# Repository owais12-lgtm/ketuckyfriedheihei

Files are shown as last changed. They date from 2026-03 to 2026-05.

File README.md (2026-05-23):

# ketuckyfriedheihei

https://github.com/user-attachments/assets/ab107a92-7bb6-4f32-aefd-921b1ff62dd6

# about

This keyboard has 74 regular keys, 8 programmable macro keys, and 1 switch within the rotary encoder

# Images







# BOM

| Name | Purpose | Quantity | Total Cost (USD) | Link | Distributor |
|---|---|---|---|---|---|
| PCB | PCB | 1 | $60.00 | [lioncircuits.com](https://www.lioncircuits.com/quote) | Lion Circuits |
| Keycaps | Keycaps | 1 | $30.00 | [curiositycaps.in](https://curiositycaps.in/products/polar-day-line-crack-side-backlit-cherry-keycaps) | Curiosity Caps |
| Akko V3 Silver | Switches | 2 | $32.00 | [stackskb.com](https://stackskb.com/store/akko-v3-silver-pro-switch-pack-of-45/) | StacksKB |
| OLED | OLED | 1 | $2.00 | [robu.in](https://robu.in/product/0-91-inch-128x32-i2c-iic-serial-blue-oled-lcd-display-module/) | Robu |
| Raspberry Pi Pico | MCU | 1 | $5.00 | [robu.in](https://robu.in/product/raspberry-pi-pico/) | Robu |

# CAD files

https://www.tinkercad.com/things/lyZ20fdyAEX-surprising-snicket

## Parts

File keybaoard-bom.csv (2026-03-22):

Name | Purpose | Quantity | Total Cost (USD) | Link | Distributor
pcb | pcb | 1 | 0.00 | https://www.lioncircuits.com/quote | lion circuits
keycaps | keycaps | 1 | 30.00 | https://curiositycaps.in/products/polar-day-line-crack-side-backlit-cherry-keycaps | curiosity caps
Akko V3 Silver | switches | 2 | 32.00 | https://stackskb.com/store/akko-v3-silver-pro-switch-pack-of-45/ | stackskb
OLED | oled | 1 | 2.00 | https://robu.in/product/0-91-inch-128x32-i2c-iic-serial-blue-oled-lcd-display-module/ | robu
Raspberry Pi Pico | MCU | 1 | 5.00 | https://robu.in/product/raspberry-pi-pico/ | robu

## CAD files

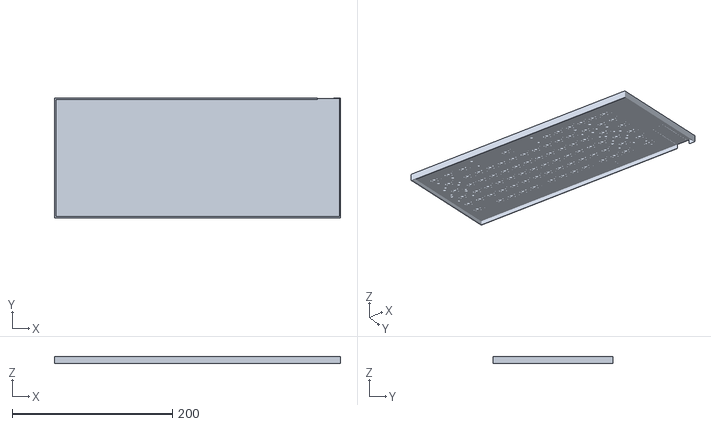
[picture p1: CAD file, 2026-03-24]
CAD/Surprising Snicket(2).stl
357.0 x 150.0 x 9.10

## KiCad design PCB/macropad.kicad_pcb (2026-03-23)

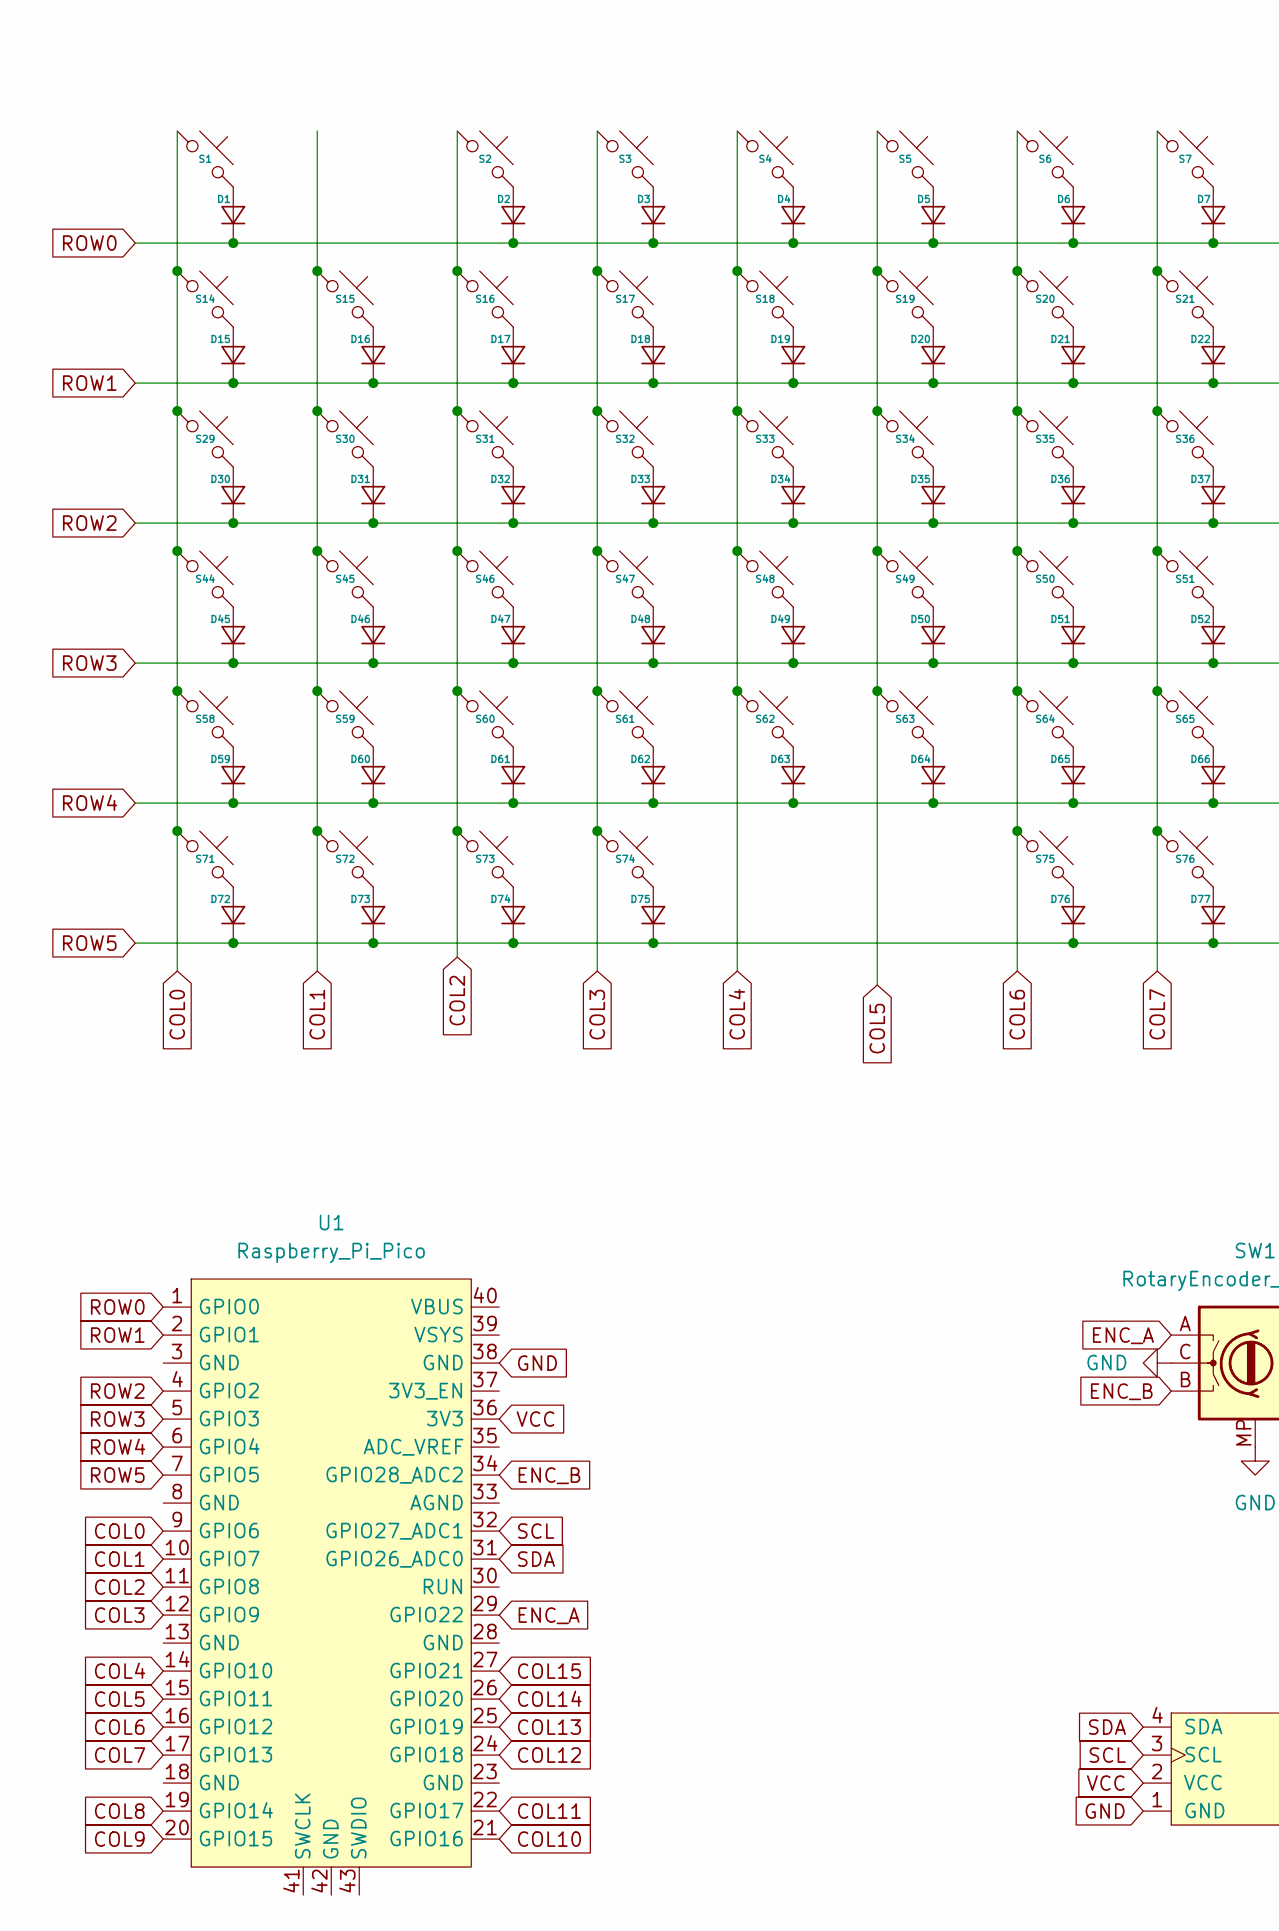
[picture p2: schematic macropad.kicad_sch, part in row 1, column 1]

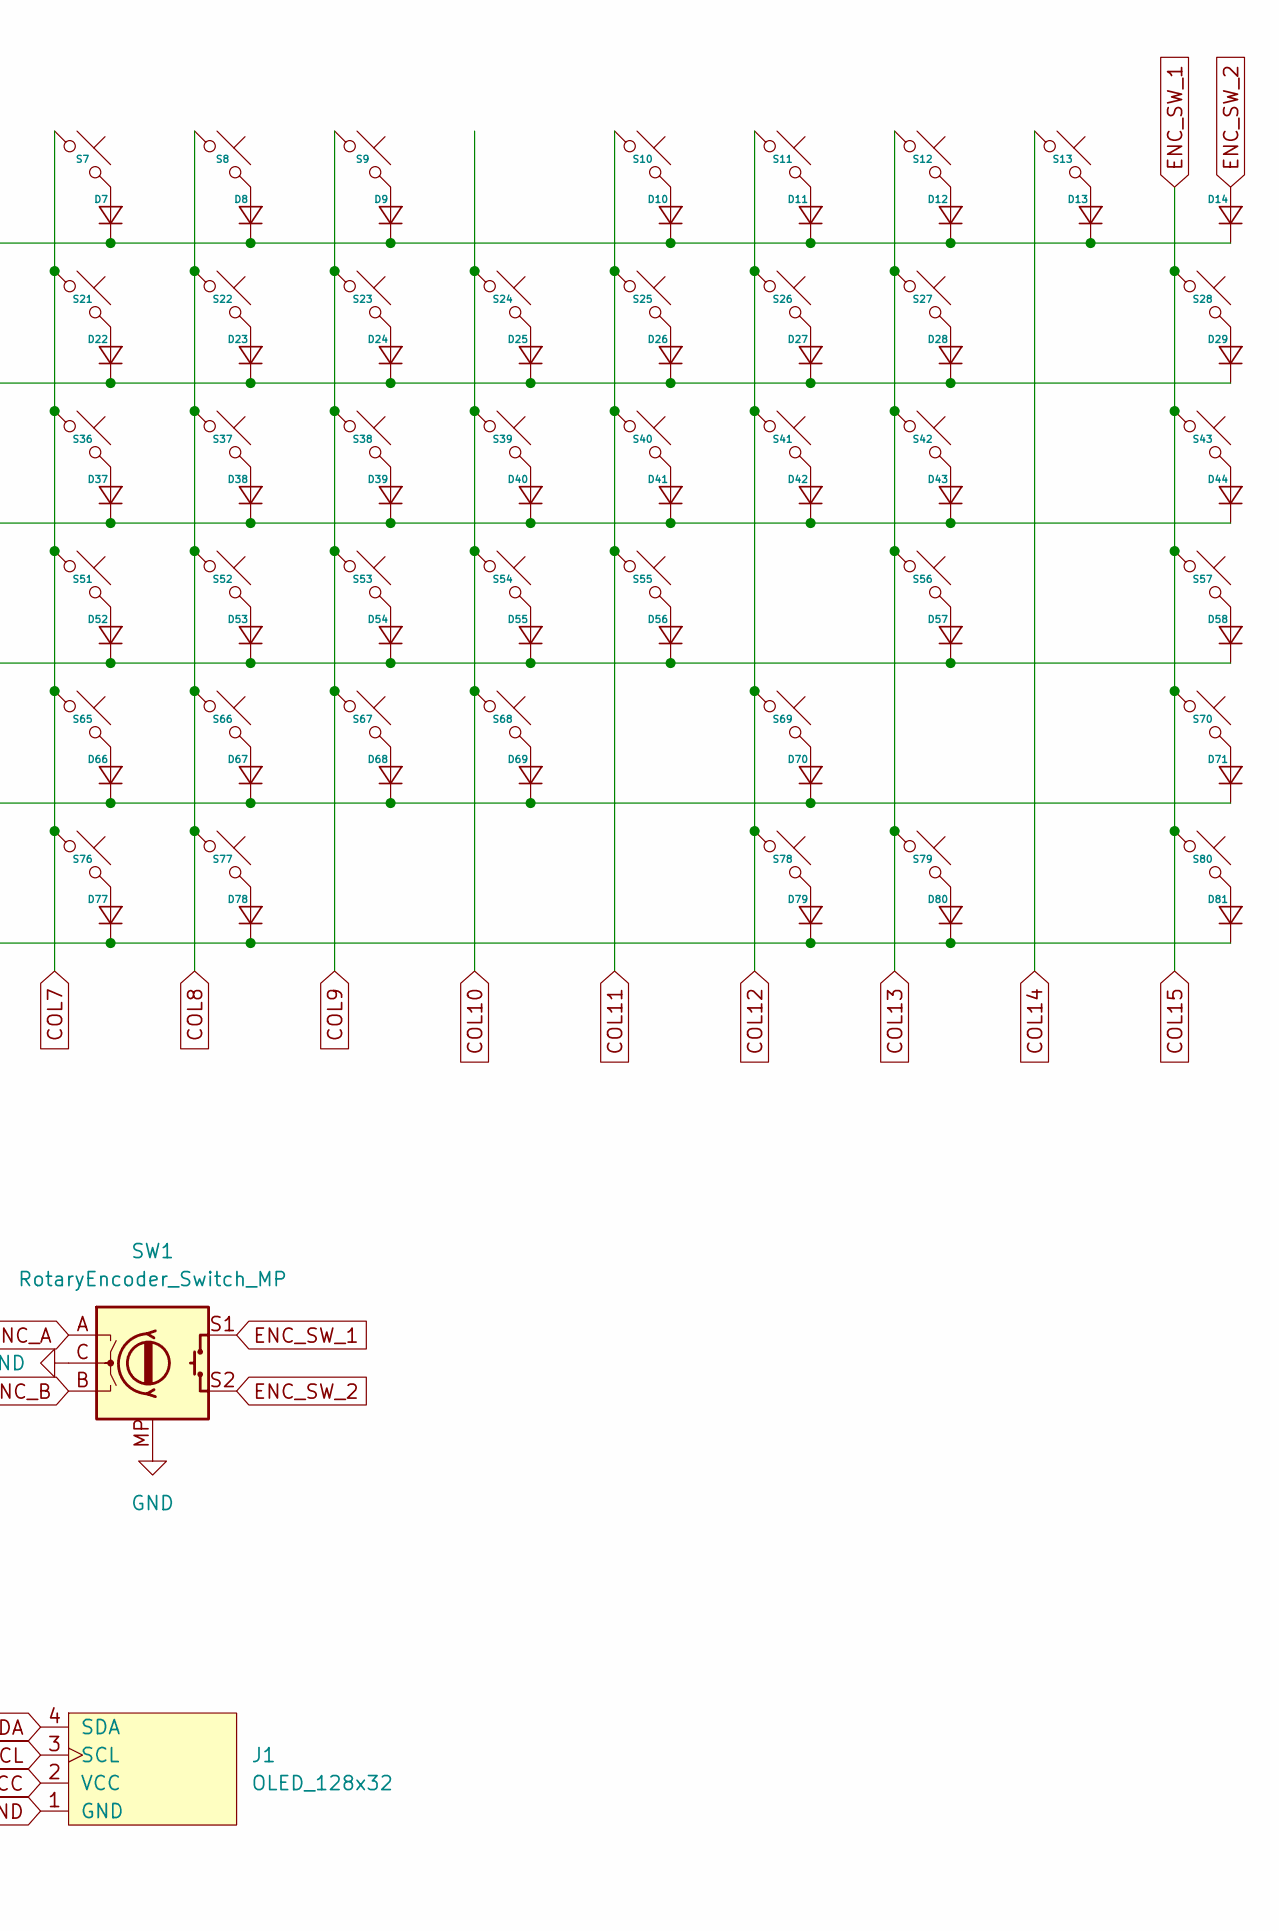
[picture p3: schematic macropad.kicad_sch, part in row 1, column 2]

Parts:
D1, D2, D3, D4, D5, D6, D7, D8, D9, D10, D11, D12, D13, D14, D15, D16, D17, D18, D19, D20, D21, D22, D23, D24, D25, D26, D27, D28, D29, D30, D31, D32, D33, D34, D35, D36, D37, D38, D39, D40, D41, D42, D43, D44, D45, D46, D47, D48, D49, D50, D51, D52, D53, D54, D55, D56, D57, D58, D59, D60, D61, D62, D63, D64, D65, D66, D67, D68, D69, D70, D71, D72, D73, D74, D75, D76, D77, D78, D79, D80, D81: Diode_DO-35
J1: OLED_128x32
S1, S2, S3, S4, S5, S6, S7, S8, S9, S10, S11, S12, S13, S14, S15, S16, S17, S18, S19, S20, S21, S22, S23, S24, S25, S26, S27, S28, S29, S30, S31, S32, S33, S34, S35, S36, S37, S38, S39, S40, S41, S42, S43, S44, S45, S46, S47, S48, S49, S50, S51, S52, S53, S54, S55, S56, S57, S58, S59, S60, S61, S62, S63, S64, S65, S66, S67, S68, S69, S70, S71, S72, S73, S74, S75, S76, S77, S78, S79, S80: MX_PCB_1.00u
SW1: RotaryEncoder_Switch_MP; RotaryEncoder_Alps_EC11E-Switch_Vertical_H20mm_MountingHoles
U1: Raspberry_Pi_Pico

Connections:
COL0: S1.1, S14.1, S29.1, S44.1, S58.1, S71.1, U1.9 (GPIO6)
COL1: S15.1, S30.1, S45.1, S59.1, S72.1, U1.10 (GPIO7)
COL2: S2.1, S16.1, S31.1, S46.1, S60.1, S73.1, U1.11 (GPIO8)
COL3: S3.1, S17.1, S32.1, S47.1, S61.1, S74.1, U1.12 (GPIO9)
COL4: S4.1, S18.1, S33.1, S48.1, S62.1, U1.14 (GPIO10)
COL5: S5.1, S19.1, S34.1, S49.1, S63.1, U1.15 (GPIO11)
COL6: S6.1, S20.1, S35.1, S50.1, S64.1, S75.1, U1.16 (GPIO12)
COL7: S7.1, S21.1, S36.1, S51.1, S65.1, S76.1, U1.17 (GPIO13)
COL8: S8.1, S22.1, S37.1, S52.1, S66.1, S77.1, U1.19 (GPIO14)
COL9: S9.1, S23.1, S38.1, S53.1, S67.1, U1.20 (GPIO15)
COL10: S24.1, S39.1, S54.1, S68.1, U1.21 (GPIO16)
COL11: S10.1, S25.1, S40.1, S55.1, U1.22 (GPIO17)
COL12: S11.1, S26.1, S41.1, S69.1, S78.1, U1.24 (GPIO18)
COL13: S12.1, S27.1, S42.1, S56.1, S79.1, U1.25 (GPIO19)
COL14: S13.1, U1.26 (GPIO20)
COL15: S28.1, S43.1, S57.1, S70.1, S80.1, SW1.S1, U1.27 (GPIO21)
ENC_A: SW1.A, U1.29 (GPIO22)
ENC_B: SW1.B, U1.34 (GPIO28_ADC2)
ENC_SW_2: D14.2 (A), SW1.S2
GND: J1.1 (GND), SW1.C, SW1.MP, U1.38 (GND)
unnamed: D1.2 (A), S1.2
unnamed: D2.2 (A), S2.2
unnamed: D3.2 (A), S3.2
unnamed: D4.2 (A), S4.2
unnamed: D5.2 (A), S5.2
unnamed: D6.2 (A), S6.2
unnamed: D7.2 (A), S7.2
unnamed: D8.2 (A), S8.2
unnamed: D9.2 (A), S9.2
unnamed: D10.2 (A), S10.2
unnamed: D11.2 (A), S11.2
unnamed: D12.2 (A), S12.2
unnamed: D13.2 (A), S13.2
unnamed: D15.2 (A), S14.2
unnamed: D16.2 (A), S15.2
unnamed: D17.2 (A), S16.2
unnamed: D18.2 (A), S17.2
unnamed: D19.2 (A), S18.2
unnamed: D20.2 (A), S19.2
unnamed: D21.2 (A), S20.2
unnamed: D22.2 (A), S21.2
unnamed: D23.2 (A), S22.2
unnamed: D24.2 (A), S23.2
unnamed: D25.2 (A), S24.2
unnamed: D26.2 (A), S25.2
unnamed: D27.2 (A), S26.2
unnamed: D28.2 (A), S27.2
unnamed: D29.2 (A), S28.2
unnamed: D30.2 (A), S29.2
unnamed: D31.2 (A), S30.2
unnamed: D32.2 (A), S31.2
unnamed: D33.2 (A), S32.2
unnamed: D34.2 (A), S33.2
unnamed: D35.2 (A), S34.2
unnamed: D36.2 (A), S35.2
unnamed: D37.2 (A), S36.2
unnamed: D38.2 (A), S37.2
unnamed: D39.2 (A), S38.2
unnamed: D40.2 (A), S39.2
unnamed: D41.2 (A), S40.2
unnamed: D42.2 (A), S41.2
unnamed: D43.2 (A), S42.2
unnamed: D44.2 (A), S43.2
unnamed: D45.2 (A), S44.2
unnamed: D46.2 (A), S45.2
unnamed: D47.2 (A), S46.2
unnamed: D48.2 (A), S47.2
unnamed: D49.2 (A), S48.2
unnamed: D50.2 (A), S49.2
unnamed: D51.2 (A), S50.2
unnamed: D52.2 (A), S51.2
unnamed: D53.2 (A), S52.2
unnamed: D54.2 (A), S53.2
unnamed: D55.2 (A), S54.2
unnamed: D56.2 (A), S55.2
unnamed: D57.2 (A), S56.2
unnamed: D58.2 (A), S57.2
unnamed: D59.2 (A), S58.2
unnamed: D60.2 (A), S59.2
unnamed: D61.2 (A), S60.2
unnamed: D62.2 (A), S61.2
unnamed: D63.2 (A), S62.2
unnamed: D64.2 (A), S63.2
unnamed: D65.2 (A), S64.2
unnamed: D66.2 (A), S65.2
unnamed: D67.2 (A), S66.2
unnamed: D68.2 (A), S67.2
unnamed: D69.2 (A), S68.2
unnamed: D70.2 (A), S69.2
unnamed: D71.2 (A), S70.2
unnamed: D72.2 (A), S71.2
unnamed: D73.2 (A), S72.2
unnamed: D74.2 (A), S73.2
unnamed: D75.2 (A), S74.2
unnamed: D76.2 (A), S75.2
unnamed: D77.2 (A), S76.2
unnamed: D78.2 (A), S77.2
unnamed: D79.2 (A), S78.2
unnamed: D80.2 (A), S79.2
unnamed: D81.2 (A), S80.2
ROW0: D1.1 (K), D2.1 (K), D3.1 (K), D4.1 (K), D5.1 (K), D6.1 (K), D7.1 (K), D8.1 (K), D9.1 (K), D10.1 (K), D11.1 (K), D12.1 (K), D13.1 (K), D14.1 (K), U1.1 (GPIO0)
ROW1: D15.1 (K), D16.1 (K), D17.1 (K), D18.1 (K), D19.1 (K), D20.1 (K), D21.1 (K), D22.1 (K), D23.1 (K), D24.1 (K), D25.1 (K), D26.1 (K), D27.1 (K), D28.1 (K), D29.1 (K), U1.2 (GPIO1)
ROW2: D30.1 (K), D31.1 (K), D32.1 (K), D33.1 (K), D34.1 (K), D35.1 (K), D36.1 (K), D37.1 (K), D38.1 (K), D39.1 (K), D40.1 (K), D41.1 (K), D42.1 (K), D43.1 (K), D44.1 (K), U1.4 (GPIO2)
ROW3: D45.1 (K), D46.1 (K), D47.1 (K), D48.1 (K), D49.1 (K), D50.1 (K), D51.1 (K), D52.1 (K), D53.1 (K), D54.1 (K), D55.1 (K), D56.1 (K), D57.1 (K), D58.1 (K), U1.5 (GPIO3)
ROW4: D59.1 (K), D60.1 (K), D61.1 (K), D62.1 (K), D63.1 (K), D64.1 (K), D65.1 (K), D66.1 (K), D67.1 (K), D68.1 (K), D69.1 (K), D70.1 (K), D71.1 (K), U1.6 (GPIO4)
ROW5: D72.1 (K), D73.1 (K), D74.1 (K), D75.1 (K), D76.1 (K), D77.1 (K), D78.1 (K), D79.1 (K), D80.1 (K), D81.1 (K), U1.7 (GPIO5)
SCL: J1.3 (SCL), U1.32 (GPIO27_ADC1)
SDA: J1.4 (SDA), U1.31 (GPIO26_ADC0)
VCC: J1.2 (VCC), U1.36 (3V3)

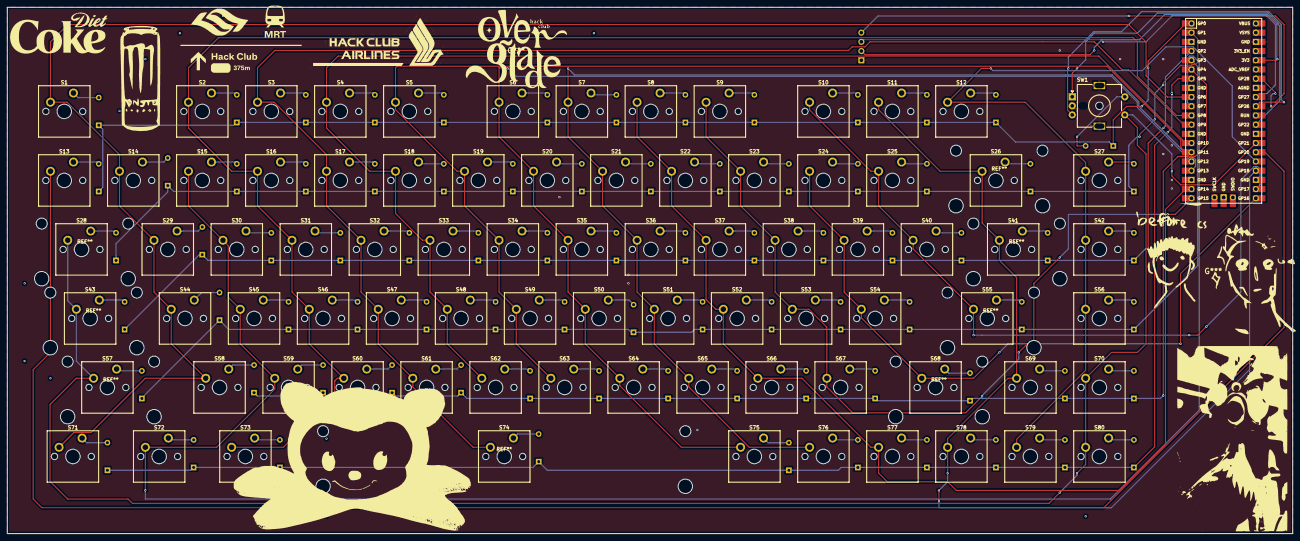
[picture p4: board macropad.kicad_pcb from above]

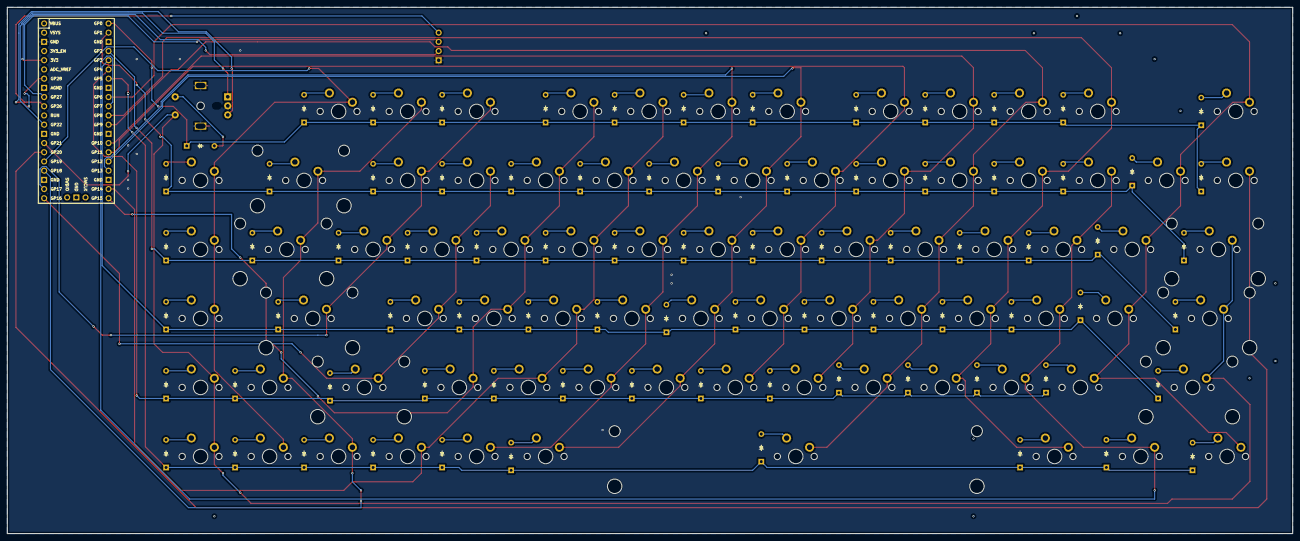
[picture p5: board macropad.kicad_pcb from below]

Board: 2 copper layers, 354.8 x 145.3 mm, 164 parts (81 on the bottom side), 109 nets.

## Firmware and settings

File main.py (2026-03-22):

import board
import busio
from kmk.kmk_keyboard import KMKKeyboard
from kmk.keys import KC
from kmk.scanners import DiodeOrientation
from kmk.modules.layers import Layers
from kmk.modules.encoder import EncoderHandler
from kmk.extensions.media_keys import MediaKeys
from kmk.modules.oled import Oled, OledData

keyboard = KMKKeyboard()

keyboard.row_pins = (
    board.GP0,
    board.GP1,
    board.GP2,
    board.GP3,
    board.GP4,
    board.GP5,
)

keyboard.col_pins = (
    board.GP6,
    board.GP7,
    board.GP8,
    board.GP9,
    board.GP10,
    board.GP11,
    board.GP12,
    board.GP13,
    board.GP14,
    board.GP15,
    board.GP16,
    board.GP17,
    board.GP18,
    board.GP19,
    board.GP20,
    board.GP21,
)

keyboard.diode_orientation = DiodeOrientation.COL2ROW

keyboard.modules.append(Layers())
keyboard.extensions.append(MediaKeys())

encoder_handler = EncoderHandler()
encoder_handler.pins = ((board.GP22, board.GP28, None),)
keyboard.modules.append(encoder_handler)

oled = Oled(
    OledData(
        corner_one={0: OledData.oled_text_entry(text="Layer: BASE", x=0, y=0)},
        corner_two={0: OledData.oled_text_entry(text="KMK Ready", x=0, y=16)},
    ),
    toDisplay=OledData.LAYER,
    i2c=lambda: busio.I2C(board.GP27, board.GP26),
)
keyboard.modules.append(oled)

___ = KC.TRNS

BASE = (
    KC.ESC,  KC.F1,   KC.F2,   KC.F3,   KC.F4,   KC.F5,   KC.F6,   KC.F7,   KC.F8,   KC.F9,   KC.F10,  KC.F11,  KC.F12,  KC.PSCR, KC.MUTE, KC.MPLY,
    KC.GRV,  KC.N1,   KC.N2,   KC.N3,   KC.N4,   KC.N5,   KC.N6,   KC.N7,   KC.N8,   KC.N9,   KC.N0,   KC.MINS, KC.EQL,  KC.BSPC, ___,     KC.DEL,
    KC.TAB,  KC.Q,    KC.W,    KC.E,    KC.R,    KC.T,    KC.Y,    KC.U,    KC.I,    KC.O,    KC.P,    KC.LBRC, KC.RBRC, KC.BSLS, ___,     KC.PGUP,
    KC.CAPS, KC.A,    KC.S,    KC.D,    KC.F,    KC.G,    KC.H,    KC.J,    KC.K,    KC.L,    KC.SCLN, KC.QUOT, ___,     KC.ENT,  ___,     KC.PGDN,
    KC.LSFT, ___,     KC.Z,    KC.X,    KC.C,    KC.V,    KC.B,    KC.N,    KC.M,    KC.COMM, KC.DOT,  KC.SLSH, ___,     KC.RSFT, KC.UP,   ___,
    KC.LCTL, KC.LGUI, KC.LALT, ___,     ___,     ___,     KC.SPC,  ___,     ___,     ___,     KC.RALT, KC.MO(1),KC.RCTL, KC.LEFT, KC.DOWN, KC.RGHT,
)

FN = (
    ___,     KC.BRID, KC.BRIU, KC.MCTL, ___,     ___,     ___,     KC.MPRV, KC.MPLY, KC.MNXT, KC.MUTE, KC.VOLD, KC.VOLU,
)

keyboard.keymap = [BASE, FN]

encoder_handler.map = (
    ((KC.VOLU, KC.VOLD),),
    ((KC.BRIU, KC.BRID),),
)

if __name__ == "__main__":
    keyboard.go()
